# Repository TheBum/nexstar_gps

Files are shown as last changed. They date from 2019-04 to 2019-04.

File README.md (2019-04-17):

# SkySync GPS clone
 
A project to build an open source Celestron SkySync GPS compatible unit. This variant includes a 128x32 pixel SSD1306 OLED display for showing position, time, and satellite information.
 
Forked from ForestTree's fork of the fantastic project by bebrown (https://github.com/bebrown/nexstar_gps).
 
## Goals
 
Construct a SkySync-compatible unit for attaching a GPS to Celestron mounts that don't already have a GPS, such as the CGEM or AVX.
 
## Parts
 
To build this, you will need:
 
* A GPS module, such as the uBlox NEO-6M. Commonly used by hoobyists for their quadcopters.
  Available for about $16.
 
* A small Arduino, such as the Pro Mini (5V version). Clones available for about $3.
 
* A TTL serial-to-USB adapter for programming the Arduino (if it does not have an on-board
  USB port already). Available for about $3.
 
* A 128x32 pixel (or larger) SSD1306 I2C OLED display.
 
## Construction
 
See [schematics diagram](eagle-Nano/Nano-schematic.png).
 
## Libraries
 
You will need to install the following libraries:
 
* TinyGPS++, available from http://arduiniana.org/libraries/tinygpsplus/.
 
* SSD1306Ascii, available through the Arduino Library Manager.
 
Also needed are the following libraries built in to the Arduino IDE:
 
* SoftwareSerial
 
* Wire
 
## Additional info
 
See this links for more info about Celestron mounts, AUX port, wiring and communication protocol:
 
https://www.nexstarsite.com/download/manuals/NexStarCommunicationProtocolV1.2.zip
https://sites.google.com/site/wayneholder/nexstar-direct-telescope-mount-control
https://www.nexstarsite.com/download/CelestronAS_PCinterface.pdf
http://www.paquettefamily.ca/nexstar/NexStar_AUX_Commands_10.pdf

The eagle-Nano folder contains the EAGLE design files for the schematic and board, as well as a zip archive ready for upload to a PCB service (e.g. https://jlcpcb.com).
 
## Attention
 
Be attentive during construction and testing your device!!! You can easy destroy the motherboard in your astro mount.

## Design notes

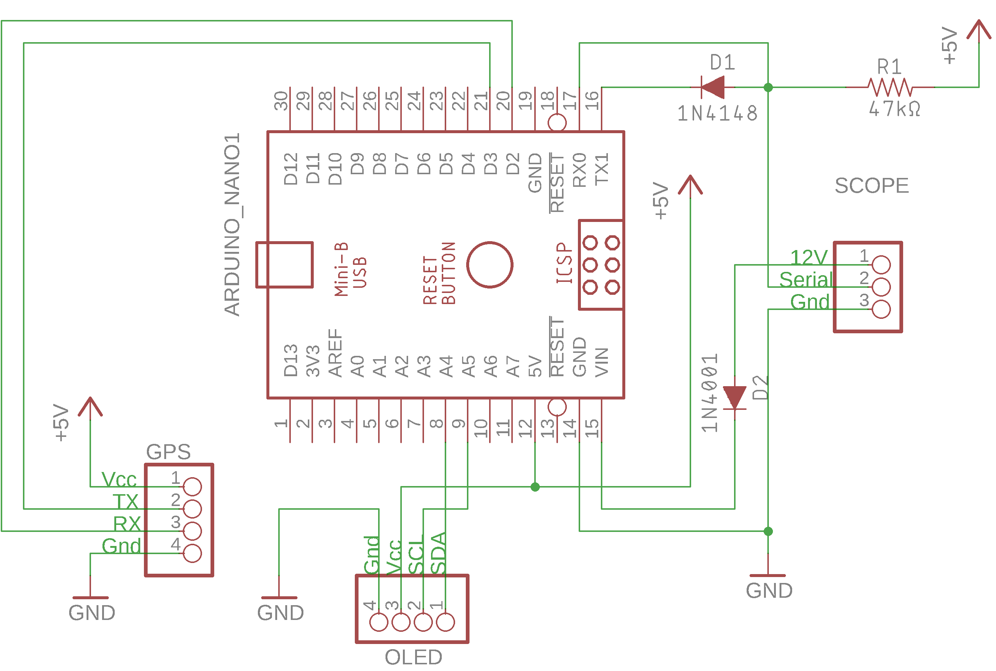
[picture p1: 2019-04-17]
eagle-Nano/Nano-schematic.png

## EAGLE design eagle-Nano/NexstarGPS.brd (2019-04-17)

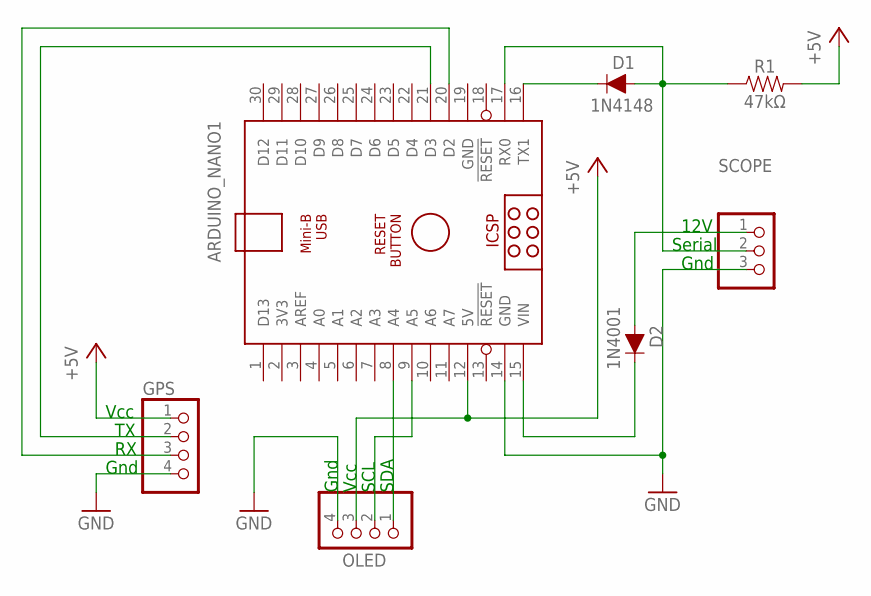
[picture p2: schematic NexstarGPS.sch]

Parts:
ARDUINO_NANO1: ARDUINO_NANO
D1: 1N4148; DIODE-1N4148
D2: 1N4001; DIODE-1N4001
GPS: PINHD-1X4; 1X04
OLED: PINHD-1X4; 1X04
R1: 47kΩ; AXIAL-0.3
SCOPE: PINHD-1X3; 1X03

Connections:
5V: ARDUINO_NANO1.12 (5V), GPS.1, OLED.3, R1.P$2 (2)
12V: ARDUINO_NANO1.15 (VIN), D2.C
GND: ARDUINO_NANO1.14 (GND), ARDUINO_NANO1.19 (GND), GPS.4, OLED.4, SCOPE.3
GPSRX: ARDUINO_NANO1.20 (D2), GPS.3
GPSTX: ARDUINO_NANO1.21 (D3), GPS.2
unnamed: D2.A, SCOPE.1
NANOTX1: ARDUINO_NANO1.16 (TX1), D1.C
OLEDSCL: ARDUINO_NANO1.9 (A5), OLED.2
OLEDSDA: ARDUINO_NANO1.8 (A4), OLED.1
SCOPESERIAL: ARDUINO_NANO1.17 (RX0), D1.A, R1.P$1 (1), SCOPE.2

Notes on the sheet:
Vcc
Gnd
Serial
12V
SDA
SCL

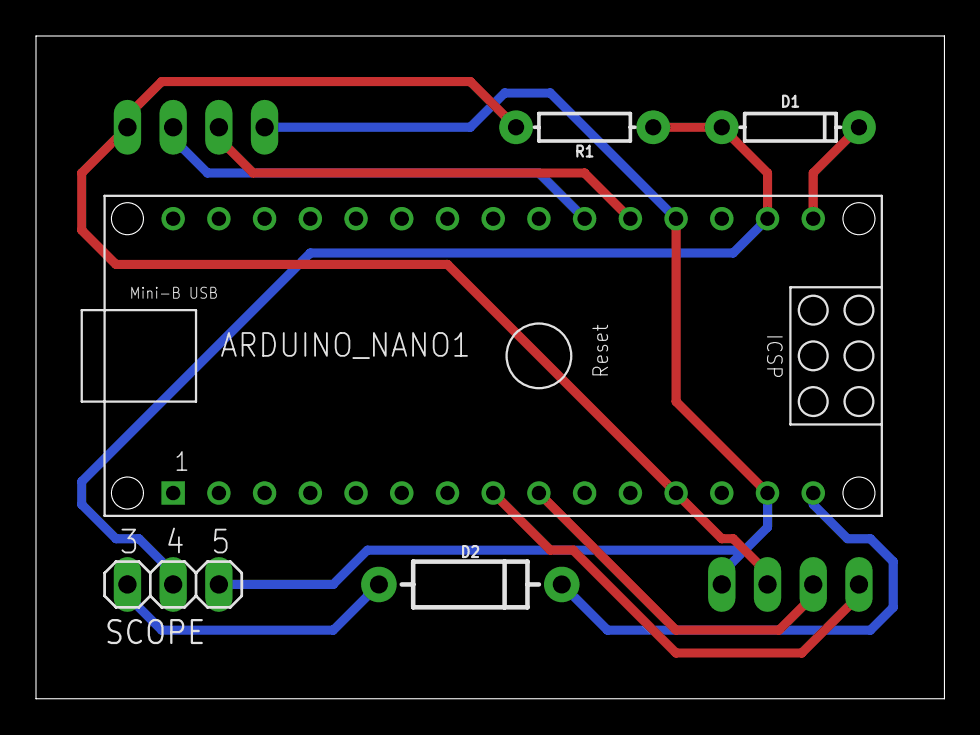
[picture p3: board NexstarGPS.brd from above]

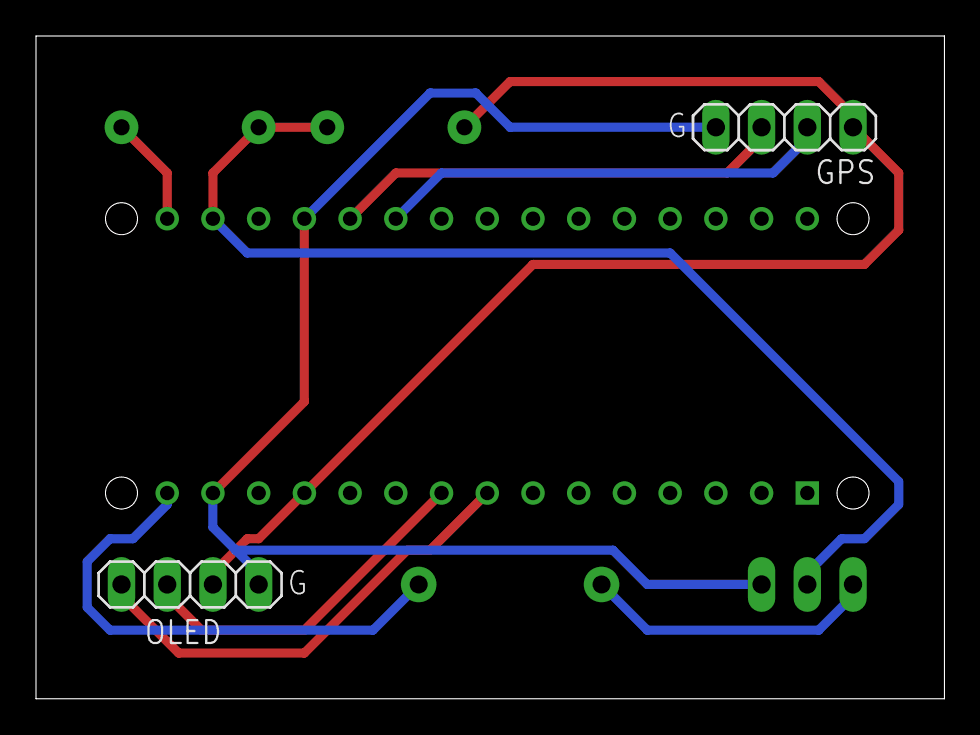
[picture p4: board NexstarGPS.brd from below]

Board: 2 copper layers, 50.5 x 36.8 mm, 7 parts (2 on the bottom side), 10 nets.

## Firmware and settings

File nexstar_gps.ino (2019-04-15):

#include <TinyGPS++.h>
#include <SoftwareSerial.h>
#include <Wire.h>
#include <SSD1306AsciiWire.h>

#include "define.h"

#define RXPIN 3
#define TXPIN 2

const int LED_COMM_ACTIVE = LED_BUILTIN;   // =13
const int LED_GPS_STATE = 12;

TinyGPSPlus gps;
SoftwareSerial ss(RXPIN, TXPIN);

SSD1306AsciiWire oled;
// 0X3C+SA0 - 0x3C or 0x3D
#define I2C_ADDRESS 0x3C
#define GPS_LAT_ROW 0
#define GPS_LON_ROW 1
#define GPS_SAT_ROW 2
#define GPS_UTC_ROW 3

TinyGPSCustom satellitesInView(gps, "GPGSV", 3);
TinyGPSCustom fixQuality(gps, "GPGGA", 6);  // 0 = invalid, 1 = GPS, 2 = DGPS, etc...
int fixQualityInt;

// For more details how convert GPS position into 24 bit format,
// see "NexStar Communication Protocol", section "GPS Commands".
// https://www.nexstarsite.com/download/manuals/NexStarCommunicationProtocolV1.2.zip
const double GPS_MULT_FACTOR = 46603.37778;  // = 2^24 / 360

#define PK_MAX_LEN 12
unsigned char packet[PK_MAX_LEN];   // Is 12 enough? What is the largest expected packet?
enum pk_state { PREAMBLE_WAIT, LENGTH_WAIT, DATA, CKSUM, DONE, VALID };
enum pk_state pkstate;
int pklen;
int pkidx;
int16_t cksum_accumulator;

int ledStateGps = LOW;
int ledStateCommActive = LOW;
unsigned long previousMillis = 0;
long blink_interval = 0;

char *lineDefs[] = { "Sat  Lat=%s", "%2.2d   Lon=%s" };

void setup() {
  // put your setup code here, to run once:
  pkstate = PREAMBLE_WAIT;
  pklen = 0;
  pkidx = 0;

  Serial.begin(19200, SERIAL_8N2);
  ss.begin(9600);
  pinMode(LED_GPS_STATE, OUTPUT);
  pinMode(LED_COMM_ACTIVE, OUTPUT);

  Wire.begin();
  Wire.setClock(400000L);
  oled.begin(&Adafruit128x32, I2C_ADDRESS);
  oled.setFont(System5x7);
  oled.clear();
}

void loop() {
  // put your main code here, to run repeatedly:

  // Feed characters from the GPS module into TinyGPS
  while (ss.available())
  {
    gps.encode(ss.read());
  }

  // Feed characters from the serial port into the packet decoder
  while (Serial.available())
    packet_decode(Serial.read());

  fixQualityInt = getGpsQuality(fixQuality.value());

  updateOled();

  // GPS quality LED indication
  if (fixQualityInt > 0) {
    // GPS fixed, LED lights continuously
    digitalWrite(LED_GPS_STATE, true);
  } else {
    if (fixQualityInt == -1) {
      // data from GPS module missing, LED fast blinking
      blink_interval = 50;
    } else {
      // GPS not fixed, LED slow blinking
      blink_interval = 250;
    }
    unsigned long currentMillis = millis();

    if (currentMillis - previousMillis >= blink_interval) {
      // save the last time you blinked the LED
      previousMillis = currentMillis;

      ledChangeStateGps();
    }
  }

  // Check if packet is valid
  if (pkstate != VALID) return;

  // Check that destination is for me
  if (packet[2] != DEV_GPS) {
    pkstate = PREAMBLE_WAIT;
    pkidx = 0;
    pklen = 0;
    return;
  }

  ledChangeStateCommActive();

  // It's for me! What's the command?
  uint8_t dest = packet[1];
  switch (packet[3])
  {
    case GPS_LINKED:
    case GPS_TIME_VALID:
      if (fixQualityInt > 0)
        pk_send(dest, packet[3], 1);
      else
        pk_send(dest, packet[3], 0);
      break;

    case GPS_GET_TIME:
      pk_send(dest, GPS_GET_TIME, gps.time.hour(), gps.time.minute(), gps.time.second());
      break;

    case GPS_GET_HW_VER:
      pk_send(dest, GPS_GET_HW_VER, GPS_HW_VER);
      break;

    case GPS_GET_YEAR:
      pk_send(dest, GPS_GET_YEAR, gps.date.year() >> 8, gps.date.year() & 0xff);
      break;

    case GPS_GET_DATE:
      pk_send(dest, GPS_GET_DATE, gps.date.month(), gps.date.day());
      break;

    case GPS_GET_LAT: {
        int32_t lat = (int32_t) (gps.location.lat() * GPS_MULT_FACTOR);
        uint8_t* latBytePtr = (uint8_t*)&lat;
        pk_send(dest, GPS_GET_LAT, latBytePtr[2], latBytePtr[1], latBytePtr[0]);
        break;
      }

    case GPS_GET_LONG: {
        int32_t lng = (int32_t) (gps.location.lng() * GPS_MULT_FACTOR);
        uint8_t* lngBytePtr = (uint8_t*)&lng;
        pk_send(dest, GPS_GET_LONG, lngBytePtr[2], lngBytePtr[1], lngBytePtr[0]);
        break;
      }

    case GPS_GET_SAT_INFO: {
        String satellitesInViewString(satellitesInView.value());
        pk_send(dest, GPS_GET_SAT_INFO, satellitesInViewString.toInt(), gps.satellites.value());
        break;
      }

    case GPS_GET_RCVR_STATUS:
      break;

    case GPS_GET_COMPASS:
      break;

    case GPS_GET_VER:
      pk_send(dest, GPS_GET_VER, 0, 1);  // Version 0.1
      break;
  }

  pkstate = PREAMBLE_WAIT;
  pklen = 0;
  pkidx = 0;
}

int getGpsQuality(const char* value) {
  String quality(value);
  if (quality.length() == 0) {
    return -1;
  } else {
    return quality.toInt();
  }
}

void packet_decode(int8_t c)
{
  switch (pkstate)
  {
    case PREAMBLE_WAIT:
      if (c == 0x3b) {
        pkstate = LENGTH_WAIT;
      }
      break;

    case LENGTH_WAIT:
      if (c < PK_MAX_LEN) {
        pklen = c;
        packet[0] = c;
        pkidx = 1;
        pkstate = DATA;
      }
      else
        pkstate = PREAMBLE_WAIT;
      break;

    case DATA:
      packet[pkidx] = c;
      pkidx++;
      if (pkidx == pklen + 1)
        pkstate = CKSUM;
      break;

    case CKSUM:
      if (pk_checksum(c))
        pkstate = VALID;
      else
        pkstate = PREAMBLE_WAIT;
      break;
  }
}

bool pk_checksum(int8_t target)
{
  int sum = 0;
  for (int i = 0; i <= pklen; i++) sum += packet[i];
  int8_t chk = (-sum) & 0xff;
  return (target == chk);
}

inline void cksum_init()
{
  cksum_accumulator = 0;
}

inline void cksum_update(uint8_t b)
{
  cksum_accumulator += b;
}

inline int8_t cksum_final()
{
  return (-cksum_accumulator) & 0xff;
}

// Send a 1-byte response
void pk_send(uint8_t dest, uint8_t id, uint8_t byte0)
{
  delayMicroseconds(500);
  cksum_init();
  // Send preamble
  Serial.write(0x3b);
  // Send length 4
  cksum_update(0x04);
  Serial.write(0x04);
  // Send src
  cksum_update(DEV_GPS);
  Serial.write((uint8_t)DEV_GPS);
  // Send dest
  cksum_update(dest);
  Serial.write(dest);
  // Send message id
  cksum_update(id);
  Serial.write(id);
  // Send byte0
  cksum_update(byte0);
  Serial.write(byte0);
  // Send checksum
  Serial.write(cksum_final());
}

// Send a 2-byte response
void pk_send(uint8_t dest, uint8_t id, uint8_t byte0, uint8_t byte1)
{
  delayMicroseconds(500);
  cksum_init();
  // Send preamble
  Serial.write(0x3b);
  // Send length 5
  cksum_update(0x05);
  Serial.write(0x05);
  // Send src
  cksum_update(DEV_GPS);
  Serial.write((uint8_t)DEV_GPS);
  // Send dest
  cksum_update(dest);
  Serial.write(dest);
  // Send message id
  cksum_update(id);
  Serial.write(id);
  // Send byte0
  cksum_update(byte0);
  Serial.write(byte0);
  // Send byte1
  cksum_update(byte1);
  Serial.write(byte1);
  // Send checksum
  Serial.write(cksum_final());
}

// Send a 3-byte response
void pk_send(uint8_t dest, uint8_t id, uint8_t byte0, uint8_t byte1, uint8_t byte2)
{
  delayMicroseconds(500);
  cksum_init();
  // Send preamble
  Serial.write(0x3b);
  // Send length 6
  cksum_update(0x06);
  Serial.write(0x06);
  // Send src
  cksum_update(DEV_GPS);
  Serial.write((uint8_t)DEV_GPS);
  // Send dest
  cksum_update(dest);
  Serial.write(dest);
  // Send message id
  cksum_update(id);
  Serial.write(id);
  // Send byte0
  cksum_update(byte0);
  Serial.write(byte0);
  // Send byte1
  cksum_update(byte1);
  Serial.write(byte1);
  // Send byte2
  cksum_update(byte2);
  Serial.write(byte2);
  // Send checksum
  Serial.write(cksum_final());
}

void ledChangeStateGps() {
  if (ledStateGps == LOW) {
    ledStateGps = HIGH;
  } else {
    ledStateGps = LOW;
  }
  digitalWrite(LED_GPS_STATE, ledStateGps);
}

void ledChangeStateCommActive() {
  if (ledStateCommActive == LOW) {
    ledStateCommActive = HIGH;
  } else {
    ledStateCommActive = LOW;
  }
  digitalWrite(LED_COMM_ACTIVE, ledStateCommActive);
}

void updateOled()
{
  // Output to the OLED display
  for (int row = 0; row < 4; ++row)
  {
    char line[50];

    switch (row)
    {
      case GPS_SAT_ROW: // Number of satellites
        if (fixQualityInt > 0)
        {
          snprintf(line, sizeof(line), "   # Sats: %02d", 
                   gps.satellites.value());
        }
        else
        {
          snprintf(line, sizeof(line), "%s",
                   ((fixQualityInt == -1) ? "    ** NO DATA **" : "  Acquiring sats..."));
        }
        break;

      case GPS_LAT_ROW: // Latitude
        if (fixQualityInt > 0)
        {
          snprintf(line, sizeof(line), " Latitude: %c%9s", 
                 ((gps.location.lat() < 0.0) ? 'S' : 'N'),
                 String(fabs(gps.location.lat()), 5).c_str());
        }
        else
        {
          snprintf(line, sizeof(line), " Latitude: ----.-----");
        }
        break;

      case GPS_LON_ROW: // Longitude
        if (fixQualityInt > 0)
        {
          snprintf(line, sizeof(line), "Longitude: %c%9s", 
                 ((gps.location.lng() < 0.0) ? 'W' : 'E'),
                 String(fabs(gps.location.lng()), 5).c_str());
        }
        else
        {
          snprintf(line, sizeof(line), "Longitude: ----.-----");
        }
        break;

      case GPS_UTC_ROW: // Date/time
        snprintf(line, sizeof(line),
                 ((fixQualityInt > 0) ? "%02d/%02d/%02d UTC %02d:%02d:%02d"
                                      : "--/--/-- UTC --:--:--"),
                 gps.date.month(), gps.date.day(), gps.date.year() % 100,
                 gps.time.hour(), gps.time.minute(), gps.time.second());
        break;
    }

    oled.setRow(row);
    oled.setCol(0);
    oled.print(line);
    oled.clearToEOL();
  }
}

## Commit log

2019-04-17 EAGLE schematic and board files
    This is for an Arduino Nano implementation. Also included are a schematic image for easy viewing and a zip archive that can be uploaded to a PCB service.
    [NexstarGPS.brd, NexstarGPS.sch]
2019-04-17 EAGLE info and new schematic link

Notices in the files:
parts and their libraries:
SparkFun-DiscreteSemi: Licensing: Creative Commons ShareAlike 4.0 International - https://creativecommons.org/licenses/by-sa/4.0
